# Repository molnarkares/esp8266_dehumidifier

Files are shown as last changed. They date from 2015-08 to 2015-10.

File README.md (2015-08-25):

# esp8266_dehumidifier
Dehumidifier controller with ESP8266

# Introduction

This embedded project is aiming to add control logic to a primitive dehumidifier like Hauser DH-400. The circuit can be mounted inside the housing of the Dehumidifier and implements the following functionalities:
* Measures temperature and humidity
* Can control the ooperation of the unit manuallly or automatically via setting a maximum desired humidity level.
* It provides visual indication and allows control of the operation via a JQUERY based web GUI. 

# Build instructions

This is an Arduino sketch that is supposed to be compiled and downloaded by Arduino for ESP8266. See installation instructions here: https://github.com/esp8266/Arduino

The sketch is using two additional libraries. The SimpleTimer is used to trigger periodic events and Adafruit's HTU21DF library is used for commmunicating with the humifity sensor. It is important that the HTU21DF library had to be extended, because the SDA and SCL pins are configurable in ESP8266. So use the fork of the library from the location referred in the git submodules.
You shalll copy these two libraries to the Arduino/libraries folder of your local installation. Usualyy this is the <user>/Documents/Arduino/libraries folder. 

## Configuration

1. The sketch contains an array of SSID/password pairs that you shall update to match your Wifi network setup.
2. You can change the IO pins easily via the SDA_PIN, SCL_PIN, RELAY_PIN  and CONTAINER_PIN macros.

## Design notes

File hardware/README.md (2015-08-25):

# esp8266_dehumidifier
Dehumidifier controller with ESP8266

# Hardware

Hardware is Designed with DesignSpark PCB v 7.1

It contains:
* Connectors to +12V power supply and relay output
* switchmode power supply
* ESP8266-07 or -012
* relay with MORSE contact
* connector to HTU21DF temperature and humidity sensor
* opto isolated input to detect that the water container is full

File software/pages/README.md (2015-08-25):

# Pages

This folder contains the work files of the web server pages. These files can be changed then compressed in order to save memory and improve response time of ESP8266 WebServer.

## Architecture

The page connsists of a single main HTML file (**index.html**) that refers to
* list.json : the json response of the web server including the sensor readings and the status of the switches
* main.css is the CSS file
* main.js contains the javascript control file that handles the periodic reading of list.json and controls the switches
* control.php - this was used only during testing. You shall replace *control.php* to *control.cgi* in main.js file when you use it in esp8266.

## Moving pages to esp8266

### General

1. Convert the file using a compressor tool. Either use the recommended ones below or another that you like better.
2. Paste the compressed file in a text editor and replace the quotation mark " to \"
3. It is recommended to break down the compressed content to multiple lines for better readability. 
4. Add '    message += F("   ' at the beginning of each line and '   ");   ' at the end of the  lines.
5. Copy-paste the formatted message to the Arduino sketch.

### index.html
You can use http://www.miniwebtool.com/html-compressor/

### main.css
You may use http://cssminifier.com/

### main.js 
You can use http://jscompress.com/

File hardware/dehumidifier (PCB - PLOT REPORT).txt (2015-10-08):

PLOT REPORT
-----------

Report File:        C:\Users\kmolnar\Dropbox\esp8266_dehumidifier\hardware\dehumidifier (PCB - PLOT REPORT).txt
Report Written:     Tuesday, August 25, 2015
Project Path:       C:\Users\kmolnar\Dropbox\esp8266_dehumidifier\hardware\dehumidifier.prj
Design Path:        C:\Users\kmolnar\Dropbox\esp8266_dehumidifier\hardware\dehumidifier.pcb
Design Title:       
Created:            8/22/2015 11:10:09 PM
Last Saved:         8/24/2015 6:33:22 PM
Editing Time:       1470 min
Units:              mm (precision 1)

Device Settings
===============

Gerber Settings
===============

    Leading zero suppression.
    G01 assumed throughout.
    Line termination <*> <CR> <LF>.
    3.5 format absolute mm.

    Format commands defined in Gerber file.
    Aperture table defined in Gerber file.
    Hardware arcs allowed.

Drill Settings
==============

    Excellon Format 1    Format 3.5 absolute in mm.
    No zero suppression.

PDF Settings
============

Combine Plots Yes

Use Bookmarks Yes

Component Details Yes

Symbol Details Yes

Link Net Names Yes

View PDF Yes

All Colors Black No

Plots Output
============

    Plot Job: "C:\Users\kmolnar\Dropbox\esp8266_dehumidifier\hardware\dehumidifier.mop"

Gerber Output
=============

C:\Users\kmolnar\Dropbox\esp8266_dehumidifier\hardware\dehumidifier - Top Silkscreen.gbr

    Layers:
    ------------------
    Top Silkscreen

    D-Code Shape  (mm)
    ---------------------
    D10    Round 0.127
    D12    Round 0.200
    D15    Round 0.254
    D98    Round 0.100

Gerber Output
=============

C:\Users\kmolnar\Dropbox\esp8266_dehumidifier\hardware\dehumidifier - Top Copper.gbr

    Layers:
    --------------
    Top Copper

    D-Code Shape  (mm)
    ----------------------------------------------
    D15    Round 0.254
    D76    Round 1.422
    D78    Round 0.813
    D99    Rectangle 1.100 X 1.800
    D100   Round 4.500
    D101   Round 2.400
    D102   Square 1.524
    D103   Rectangle 1.016 X 1.219
    D104   Rectangle 1.397 X 1.524  Rotation 90
    D105   Round 1.400
    D106   Square 1.400
    D107   Rectangle 1.397 X 1.524
    D108   Round 2.200
    D109   Rectangle 0.700 X 0.500  Rotation 90
    D110   Rectangle 0.550 X 1.000  Rotation 90
    D111   Rectangle 1.600 X 1.600  Rotation 90
    D112   Round 1.700
    D113   Rectangle 1.016 X 2.032
    D114   Round 1.600
    D115   Round 1.000

Gerber Output
=============

C:\Users\kmolnar\Dropbox\esp8266_dehumidifier\hardware\dehumidifier - Top Solder Mask.gbr

    Layers:
    -------------------
    Top Solder Mask

    D-Code Shape  (mm)
    ----------------------------------------------
    D116   Rectangle 1.252 X 1.952
    D117   Round 4.652
    D118   Round 2.552
    D119   Square 1.676
    D120   Rectangle 1.168 X 1.372
    D121   Rectangle 1.549 X 1.676  Rotation 90
    D122   Round 1.552
    D123   Square 1.552
    D124   Rectangle 1.549 X 1.676
    D125   Round 2.352
    D126   Rectangle 0.852 X 0.652  Rotation 90
    D127   Rectangle 0.702 X 1.152  Rotation 90
    D128   Rectangle 1.752 X 1.752  Rotation 90
    D129   Round 1.852
    D130   Rectangle 1.168 X 2.184

Gerber Output
=============

C:\Users\kmolnar\Dropbox\esp8266_dehumidifier\hardware\dehumidifier - Bottom Copper.gbr

    Layers:
    -----------------
    Bottom Copper

    D-Code Shape  (mm)
    ---------------------------------
    D10    Round 0.127
    D15    Round 0.254
    D76    Round 1.422
    D78    Round 0.813
    D100   Round 4.500
    D101   Round 2.400
    D102   Square 1.524
    D105   Round 1.400
    D106   Square 1.400
    D108   Round 2.200
    D112   Round 1.700
    D113   Rectangle 1.016 X 2.032
    D114   Round 1.600

Gerber Output
=============

C:\Users\kmolnar\Dropbox\esp8266_dehumidifier\hardware\dehumidifier - Bottom Solder Mask.gbr

    Layers:
    ----------------------
    Bottom Solder Mask

    D-Code Shape  (mm)
    ---------------------------------
    D117   Round 4.652
    D118   Round 2.552
    D119   Square 1.676
    D122   Round 1.552
    D123   Square 1.552
    D125   Round 2.352
    D129   Round 1.852
    D130   Rectangle 1.168 X 2.184

NC Drill Output
===============

C:\Users\kmolnar\Dropbox\esp8266_dehumidifier\hardware\dehumidifier - Drill Data - [Through Hole].drl

    Output:
    ---------------------------
    Plated Round Drill Holes
    Plated Slots
    Plated Board Outlines

    Tool  Size         Count   ID
    ------------------------------------
    T001  000.40640 mm 17    K
    T002  000.76200 mm 2     D
    T003  000.80000 mm 3     B
    T004  000.81280 mm 6     E
    T005  000.88900 mm 13    F
    T006  001.30000 mm 5     A
    T007  001.40000 mm 4     M
    T008  001.50000 mm 2     C
    T009  003.10000 mm 2     L
    ------------------------------------
    Total              54
    ------------------------------------

C:\Users\kmolnar\Dropbox\esp8266_dehumidifier\hardware\dehumidifier - Drill Data - [Through Hole] (Unplated).drl

    Output:
    -----------------------------
    Unplated Round Drill Holes
    Unplated Slots
    Unplated Board Outlines

    Tool  Size         Count   ID
    ------------------------------------
    T001  000.63500 mm 1
    ------------------------------------
    Total              1
    ------------------------------------

Gerber Output
=============

C:\Users\kmolnar\Dropbox\esp8266_dehumidifier\hardware\dehumidifier - Outline.gbr

    Layers:
    ------------------
    Board Outlines

    D-Code Shape  (mm)
    ---------------------
    D10    Round 0.127

PDF Output
==========

    Layer
    ---------------
    Top Copper
    Top Silkscreen

End Of Report.

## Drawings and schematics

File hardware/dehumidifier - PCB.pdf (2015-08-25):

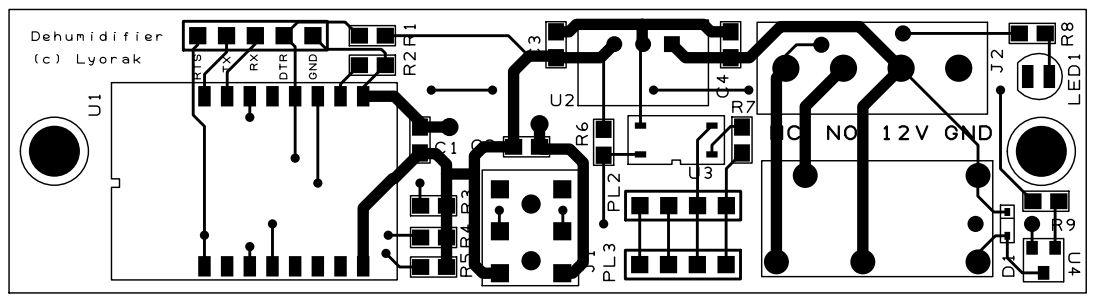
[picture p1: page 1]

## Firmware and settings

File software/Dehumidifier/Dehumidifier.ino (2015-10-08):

#include <ESP8266WiFi.h>
#include <WiFiClient.h>
#include <ESP8266WebServer.h>
#include <ESP8266mDNS.h>
#include <Wire.h>
#include <Adafruit_HTU21DF.h>
#include <EEPROM.h>
#include <SimpleTimer.h>
#include <ping.h>
 
typedef struct {
  const char *ssid;
  const char *password;
  const char *shortname;
}aps_t;

const aps_t *myaps = NULL;

const aps_t aps[] = {
  {
  .ssid = "xxxx",
  .password = "xxxxx",
  .shortname = "esp8266-xxx"
  },
  {
  .ssid = "yyyyyy",
  .password = "yyyyy",
  .shortname = "esp8266-yyyy"
  },
};


MDNSResponder mdns;

ESP8266WebServer server(80);
SimpleTimer timer;
int configTimerId = -1;


typedef struct {
  bool autocontrol;
  bool manual;
  int     desiredval;
  int     validMagic;
}t_settings;

t_settings settings;

#define VALIDMAGIC  0xcccc
#define WATCHCOUNT  10
const t_settings ref_settings = {
  .autocontrol = false,
  .manual = false,
  .desiredval = 60,
  .validMagic = VALIDMAGIC
};

int watch_count = WATCHCOUNT;

float lastTemp = 0.0;
float lastHum = 0.0;

bool serverLock = false;

const float hist = 0.5;

#define SDA_PIN 2
#define SCL_PIN 0
#define RELAY_PIN 4
#define CONTAINER_PIN 16


Adafruit_HTU21DF htu = Adafruit_HTU21DF(SDA_PIN,SCL_PIN);

void homePage();
void mainCss();
void mainJs();
void listJson();
void controlFun();
void wifiwatch();
void saveEEPROM();
bool isContainerFull();

void setup(void){
  pinMode(RELAY_PIN, OUTPUT);
  digitalWrite(RELAY_PIN, 0);
  Serial.begin(115200);

  pinMode(CONTAINER_PIN, INPUT);

  
  EEPROM.begin(sizeof(t_settings));
  for(int ectr = 0; ectr < sizeof(t_settings);ectr++) {
    uint8 tmp_8 = EEPROM.read(ectr);
    (reinterpret_cast<uint8*>(&settings))[ectr] = tmp_8;
  }
  if(settings.validMagic != VALIDMAGIC) {
    settings = ref_settings;
    Serial.println("Settings restored from reference");
  }else {
    Serial.println("Settings restored from EEPROM");
  }
  
  Serial.println("EEPROM values:");
  Serial.print("autocontrol: ");
  Serial.println(settings.autocontrol);
  Serial.print("manual: ");
  Serial.println(settings.manual);
  Serial.print("desiredval: ");
  Serial.println(settings.desiredval);

  bool foundWifi  = false;
  int foundctr = 20;
  while(!foundWifi) {
    int8_t numAPs = WiFi.scanNetworks();
    for(int8_t idxAP = 0; (idxAP < numAPs) && (!foundWifi); idxAP ++ ) {
      const char* foundAP = WiFi.SSID(idxAP);
      Serial.print("Searching for known AP with name '");
      Serial.print(foundAP);
      Serial.println("'.");
      for(int idxS = 0; idxS < (sizeof(aps) / sizeof(aps_t));idxS++) {
        Serial.print(".");
        if(!strcmp(foundAP,aps[idxS].ssid)) {
          Serial.println("SSID match!");
          myaps = &aps[idxS];
          WiFi.begin(myaps->ssid, myaps->password);
          foundWifi = true;          
          break;
        }
      }
    }
    /* We try for 20 sec then enable the POWER and mocking a standard dehumidifier without intelligence */
    if(foundctr) {
      foundctr--;      
    }else {
      digitalWrite(RELAY_PIN, 1);
    }
    delay(1000);
  }
  //WiFi.begin(ssid, password);
  Serial.println("");

  // Wait for connection
  while (WiFi.status() != WL_CONNECTED) {
    delay(500);
    Serial.print(".");
  }
  Serial.println("");
  Serial.println("Connected.");
//  Serial.println(ssid);
  Serial.print("IP address: ");
  Serial.println(WiFi.localIP());
  
  if (mdns.begin(myaps->shortname)) {
    Serial.println("MDNS responder started");
  }
  
  server.on("/", homePage);
  server.on("/main.css", mainCss);
  server.on("/main.js", mainJs);
  server.on("/list.json", listJson);
  server.on("/control.cgi", controlCgi);
  
 
  server.begin();
  Serial.println("HTTP server started");

  if (!htu.begin()) {
   Serial.println("Couldn't find sensor!");
  }
  configTimerId = timer.setInterval(15000, saveEEPROM);
  timer.disable(configTimerId);
  timer.setInterval(1000, controlFun);
  timer.setInterval(30000,wifiwatch);
}

void loop(void){
  server.handleClient();
  yield();
  timer.run();
} 

void homePage() { /* http://www.miniwebtool.com/html-compressor/ */
    String message;
    message  = F("<!DOCTYPE html><html><head><meta name='viewport' content='width=device-width, initial-scale=1' /><title>Dehumidifier</title>");
    message += F("<link rel=\"stylesheet\" href=\"http://code.jquery.com/mobile/1.4.5/jquery.mobile-1.4.5.min.css\"><link rel='stylesheet' href='main.css' />");
    message += F("<script src=\"http://code.jquery.com/jquery-1.11.1.min.js\"></script><script src=\"http://code.jquery.com/mobile/1.4.5/jquery.mobile-1.4.5.min.js\"></script>");
    message += F("<script src='//stevenlevithan.com/assets/misc/date.format.js'></script><script src='main.js'></script></head><body><div id='main' data-role='page'>");
    message += F("<div data-role='header' data-position='fixed'><h3>Temperature and Humidity data</h3></div><div data-role='content'>");
    message += F("<ul id='list' data-role='listview' data-inset='true'></ul><div class=\"ui-field-contain\"><label for=\"autocontrol\">Auto control:</label>");
    message += F("<select name=\"autocontrol\" id=\"autocontrol\" data-role=\"flipswitch\"><option value=\"off\">Off</option><option value=\"on\">On</option></select>");
    message += F("</div><div class=\"ui-field-contain\"><label for=\"mancontrol\">Manual control:</label><select name=\"mancontrol\" id=\"mancontrol\" data-role=\"flipswitch\">");
    message += F("<option value=\"off\">Off</option><option value=\"on\">On</option></select></div><div class=\"ui-field-contain\"><label for=\"water-container\">Water container:</label>");
    message += F("<select name=\"water-container\" id=\"water-container\" disabled = \"disabled\" data-role=\"flipswitch\"><option value=\"off\">OK</option><option value=\"on\">Full</option></select>");
    message += F("</div><form><label for=\"humset\">Desired humidity:</label><input name=\"humset\" id=\"humset\" min=\"0\" max=\"100\" type=\"range\"></form><p id='info'></p></div></div></body></html>");
    server.send(200, "text/html", message);
}

void mainCss() {  /* http://cssminifier.com/ */
  	String message;
    message += F(".ui-li-aside,.ui-li-aside>sup{font-size:x-large}.ui-li-aside{font-weight:700}#info{margin-top:10px;text-align:center;font-size:small}.custom-size-flipswitch.ui-flipswitch ");
    message += F(".ui-btn.ui-flipswitch-on{text-indent:-3.9em}.custom-size-flipswitch.ui-flipswitch ");
    message += F(".ui-flipswitch-off{text-indent:1em}.custom-size-flipswitch.ui-flipswitch{width:7.875em}.custom-size-flipswitch.ui-flipswitch.ui-flipswitch-active{padding-left:6em;width:1.875em}");
    message += F("@media (min-width:28em){.ui-field-contain>label+.custom-size-flipswitch.ui-flipswitch{width:1.875em}}");
    server.send(200, "text/css", message);
}

void mainJs() { /*  http://jscompress.com/ */
  	String message;
    message  = F("function processJson(){$.getJSON(\"./list.json\",function(t){var e=[];e.push('<li><a><h3>Temperature</h3><p class=\"ui-li-aside\"><sup>'+t.temp.toFixed(1)+'&deg;");
    message += F("C</sup></p></a></li><li><a><h3>Humidity</h3><p class=\"ui-li-aside\"><sup>'+t.hum.toFixed(1)+\"&#37</sup></p></a></li>\"),");
    message += F("$(\"#list\").html(e.join(\"\")).trigger(\"create\").listview(\"refresh\"),$(\"#info\").html(\"Uptime: \"+toTime(t.uptime)+\" (\"+t.free+\" bytes free)\"),");
    message += F("$(\"#autocontrol\").val(t.auto).flipswitch(\"refresh\"),$(\"#mancontrol\").val(t.manual).flipswitch(\"refresh\"),$(\"#water-container\").val(t.full).flipswitch(\"refresh\"),");
    message += F("$(\"#humset\").val(t.desired).slider(\"refresh\"),jsonLoaded=!0}),setTimeout(processJson,5e3)}function addnotify(){this.notify=function()");
    message += F("{jsonLoaded&&$.post(\"control.cgi\",{manual:$(\"#mancontrol\").val(),auto:$(\"#autocontrol\").val(),desired:$(\"#humset\").val()})},");
    message += F("$(\"#autocontrol\").change(function(){\"on\"===$(\"#autocontrol\").val()?($(\"#mancontrol\").flipswitch(\"disable\"),");
    message += F("$(\"#humset\").slider(\"enable\")):($(\"#mancontrol\").flipswitch(\"enable\"),$(\"#humset\").slider(\"disable\")),notify()}),$(\"#mancontrol\").change(notify),");
    message += F("$(\"#humset\").on(\"slidestop\",notify)}function toTime(t){var e=parseInt(t),o=\"\";this.toStr=function(t){var e=\"\";return 10>t&&(e=\"0\"),e+t.toString()};");
    message += F("var i=e%1e3;e-=i,e/=1e3;var n=e%60;e-=n,e/=60;var s=e%60;e-=s;var a=e/=60;return o=toStr(a)+\":\"+toStr(s)+\":\"+toStr(n)}$(document).ready(function()");
    message += F("{processJson(),addnotify()});var jsonLoaded=!1;");
    server.send(200, "application/javascript", message);
}


void controlCgi() {
    bool ret = false;
    noInterrupts();   //lock needed to avoid ESP8266 crash when more than one clients are trying to acccess the page
    if (serverLock) {
      ret = true;
    }else {
      serverLock = true;
    }
    interrupts();
    if(ret) return;
    
    settings.manual = server.arg("manual") == "on" ? true:false;
    settings.autocontrol = server.arg("auto")  == "on" ? true:false;
    settings.desiredval  = server.arg("desired").toInt();

    for(int ectr = 0; ectr < sizeof(t_settings);ectr++) {
        EEPROM.write(ectr,(reinterpret_cast<uint8*>(&settings))[ectr]);
    }
    timer.enable(configTimerId);
    if(settings.manual) {
        digitalWrite(RELAY_PIN, 1);
    }else {
        digitalWrite(RELAY_PIN, 0);
    }
    String message;
    message  = F("<!DOCTYPE html><html><body>OK</body></html>");
    server.send(200, "text/html", message);
    noInterrupts();
    serverLock = false;
    interrupts();
}

void listJson() {
  	String message;
    message  = F("{");
    message += F("    \"temp\":");
    message += String(lastTemp);
    message += F(",");
    message += F("  \"hum\":");
    message += String(lastHum);
    message += F(",");
    message += F("  \"uptime\":");
    message += String(millis());
    message += F(",");
    message += F("  \"free\":");
    message += String(ESP.getFreeHeap());
    message += F(",");
    message += F("  \"auto\":");
    message += settings.autocontrol == true ? "\"on\"" : "\"off\"";
    message += F(",");
    message += F("  \"manual\":");
    message += settings.manual  == true ? "\"on\"" : "\"off\"";
    message += F(",");
    message += F("  \"desired\":");
    message += String(settings.desiredval);
    message += F(",");
    message += F("  \"full\":");
    message += isContainerFull() ? "\"on\"" : "\"off\"";
    message += F("}");
    server.send(200, "application/json", message);
    timer.restartTimer(configTimerId);
}

void controlFun() {
    lastTemp = htu.readTemperature();
    yield();
    lastHum = htu.readHumidity();
    yield();
    if(settings.autocontrol) {
        float tmpDesired = (float)settings.desiredval;
        if((lastHum-tmpDesired) > hist) {
            digitalWrite(RELAY_PIN, 1);
            settings.manual = true;
        }else {
            digitalWrite(RELAY_PIN, 0);
            settings.manual = false;      
        }
    }
}

void saveEEPROM() {
  timer.disable(configTimerId);
  EEPROM.commit();
  noInterrupts();
  serverLock = false;
  interrupts();
  yield();
}


bool isContainerFull() {
  return (!digitalRead(CONTAINER_PIN));
}


void wifiwatch(void) {
  if(WiFi.status() != WL_CONNECTED) {
    watch_count--;
  }else {
    watch_count = WATCHCOUNT;
  }
  if(!watch_count) {
    ESP.restart();
  }
}

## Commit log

2015-08-25 added hardware files
    [dehumidifier.sch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]
2015-08-25 added human readable schematic and PDF plus readme
2015-10-08 added housekeeping
    [dehumidifier - Bottom Copper.gbr, dehumidifier - Bottom Solder Mask.gbr, dehumidifier - Drill Data - [Through Hole] (Unplated).drl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]
